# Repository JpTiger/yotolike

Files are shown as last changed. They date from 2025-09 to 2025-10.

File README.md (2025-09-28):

# "Yotolike" Music Box
A homemade audio player for kids that uses RFID cards and a Raspberry Pi Zero W 2, similar to a Yoto Player or Yoto Mini.

This is based on [jmcrory's The Pi Must Go On project](https://www.instructables.com/The-Pi-Must-Go-On-Pi-powered-RFID-Musical-Box/) and would not be anything close to possible without his work. His version differs from mine in a few respects: it uses a full size pi instead of a pi zero, uses usb spearkers insteadd of a HAT, is always plugged in instead of battery powered, doesn't have a volume knob, and doesn't have a 3D-printed case. A few of the script functions also didn't work for me without a lot of vibe-coded modifications which I suspect is due to changes in how underlying libraries are handled since he wrote his instructions.

The basic steps to making the version described in this repo are:

1. [Gather all materials](https://github.com/JpTiger/yotolike/blob/main/hardware/BOM/bom.md)
2. Put together the HATs and the pi
3. Wire everything to the exposed GPIO pins [as shown in this diagram](https://html-preview.github.io/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). This involved some soldering in my case to get the pins onto the RFID reader and to make the momentary button work jumper cables
4. Install Bookwork Raspbian lite via Raspbian imager with SSH enabled and wifi details included to a microsd and boot the pi for the first time
5. SSH in and update everything in Raspbian
6. use raspi-config to activate i2c, spi, and serial interfaces
7. edit /boot/firmware/config.txt to add/uncomment a couple lines to get the sound card working:
  - `dtparam=i2c_arm=on dtparam=audio=off`
  - `dtoverlay=wm8960-soundcard`
  - test speakers. Figuring this out took me a truly stupid amount of time so I hope it's as simple as following the above for you.
8. install python 3
  - `sudo apt-get install python3-dev python3-pip`
9. make a project directory (in my case /home/joel/musicbox)
10. use pip to install spidev and mfrc522
11. make write.py (standard version in [the jmcrory tutorial](https://www.instructables.com/The-Pi-Must-Go-On-Pi-powered-RFID-Musical-Box/))
12. use write.py to write to a card or two
13. copy over [Read.py](https://github.com/JpTiger/yotolike/blob/main/src/Read.py)
14. use [the power button setup script](https://github.com/JpTiger/yotolike/blob/main/scripts/momentary_pi_button_setup.sh)
15. create the musicbox systemd service and make it run on boot
  - `sudo systemctl daemon-reload`
  - `sudo systemctl enable musicbox.service`
  - `sudo systemctl start musicbox.service`
16. reboot, test one of the cards you wrote to see if it's all working
17. print the case, and [assemble everythig inside it](https://github.com/JpTiger/yotolike/blob/main/hardware/case/readme.md)

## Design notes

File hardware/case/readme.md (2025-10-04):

# Music Box Case (Onshape Design)

This folder has the stls from the case I designed in OnShape, but you may want to modify and export them yourself - I've got my daughter's name on mine for example, and it's likely your micro-usb to usb c adapter will have slightly different dimensions since the one I used seems to have disappeared. I'd suggest editing the part studio for the UPS HAT, which has the adapter built into it. You'll need calipers.

## Onshape link
- [You can view and edit the design in Onshape here](https://cad.onshape.com/documents/fd9248d9a8604b9996927086/w/dc4fd8e55b442b9873bcca82/e/b2e9d4da9e644a747f961f8a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)

## Exports
If you want to just try the version I used, STL files for 3D printing are included in the [`exports/`](exports/) folder:
- Case - card and reader stand.stl
- Case - Container.stl
- Case - Lid.stl
- Case - switch shield.stl
- Case - ups switch nub.stl

I suggest assembling the case by:
1. printing all parts 
2. inserting the speakers into the main container
3. attaching the RFID reader to the card and reader stand
4. instering the card and reader stand into the T-shaped slot that matches the bottom of it
5. putting the little switch shield on the switch of the UPS
6. instering the pi and hat stack (without the USB C adapter) into the space for them in the container
7. insterting the USB C adapter in from the hole of the container into the microusb slot
8. using poster putty or(if you're confident and dexterous) hot glue or to attach the clear PETG filament to the LEDs on the pi and UPS on one end and to the holes in the container on the other. I interted a long strand through the holes, poked it with poster putty on a toothpick until it stuck direclty onto the LEDs, then trimmed the other end of the filament at the hole end.
9. Installing the rotary encoder, tightenting, and then the same with the momentary button
10. adding the ups switch nub to the switch from the outside
11. adding the lid

If your rotraty encoder didn't come with a knob, you may need to print that as well. [This one worked for me.](https://www.thingiverse.com/thing:2549137)

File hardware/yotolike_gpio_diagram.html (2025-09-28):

# 🔌 Raspberry Pi GPIO Connection Diagram

Raspberry Pi 40-Pin GPIO Header

1 3V3

3.3V Power - RFID Reader

2 5V

3 SDA

GPIO 2 - WM8960 I2C SDA

4 5V

5 SCL

GPIO 3 - WM8960 I2C SCL + Button Normal Open

6 GND

Ground - Button Common

7 4

GPIO 4 - Button Normal Closed

8 14

GPIO 14 - LED Anode

9 GND

10 15

11 17

GPIO 17 - WM8960 Button

12 18

GPIO 18 - WM8960 I2S CLK

13 27

14 GND

15 22

16 23

GPIO 23 - RFID SCK

17 3V3

3.3V Power - Rotary Encoder VCC

18 24

GPIO 24 - RFID SDA

19 10

GPIO 10 - RFID MOSI

20 GND

21 9

GPIO 9 - RFID MISO

22 25

GPIO 25 - RFID RST

23 11

24 8

25 GND

26 7

27 0

28 1

29 5

30 GND

Ground - RFID Reader

31 6

32 12

33 13

GPIO 13 - Rotary Encoder SW

34 GND

Ground - Rotary Encoder

35 19

GPIO 19 - WM8960 LRCLK

36 16

GPIO 16 - Rotary Encoder DT

37 26

GPIO 26 - Rotary Encoder CLK

38 20

GPIO 20 - WM8960 ADC

39 GND

Ground - LED Cathode

40 21

GPIO 21 - WM8960 DAC

### 🏷️ RFID Reader (RC522)

SDA Pin 18 (GPIO 24)

SCK Pin 16 (GPIO 23)

MOSI Pin 19 (GPIO 10)

MISO Pin 21 (GPIO 9)

RST Pin 22 (GPIO 25)

3.3V Pin 1

GND Pin 30

### 🎵 WM8960 Audio HAT

SDA (I2C) Pin 3 (GPIO 2)

SCL (I2C) Pin 5 (shared) (GPIO 3)

CLK (I2S) Pin 12 (GPIO 18)

LRCLK (I2S) Pin 35 (GPIO 19)

ADC (I2S) Pin 38 (GPIO 20)

DAC (I2S) Pin 40 (GPIO 21)

BUTTON Pin 11 (GPIO 17)

### 🎛️ Rotary Encoder

CLK Pin 37 (GPIO 26)

DT Pin 36 (GPIO 16)

SW (Button) Pin 33 (GPIO 13)

VCC Pin 17 (3.3V)

GND Pin 34

### 🔘 Button & LED

LED Anode (+) (Red) Pin 8 (GPIO 14)

LED Cathode (-) (Black) Pin 39 (GND)

Button Normal Close (Blue) Pin 7 (GPIO 4)

Button Normal Open (Green) Pin 5 (shared) (GPIO 3)

Button Ground (Yellow) Pin 6 (GND)

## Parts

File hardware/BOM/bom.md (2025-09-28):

# Bill of Materials
In other words, this is everything I bought for the project.

| Item | Qty | Example Link | Notes |
|---|----:|---|---|
| Raspberry Pi Zero 2 W (with soldered header) | 1 | [PiShop US](https://www.pishop.us/product/raspberry-pi-zero-2w-with-headers/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) | Main controller |
| Waveshare WM8960 Audio HAT (with speakers) | 1 | [Waveshare](https://www.waveshare.com/wm8960-audio-hat.htm) | Stereo audio output |
| Waveshare UPS HAT (C) | 1 | [Waveshare](https://www.waveshare.com/ups-hat-c.htm) | Battery backup and safe shutdown |
| Rotary Encoder | 1 | [eBay](https://www.ebay.com/itm/314583808281) | For volume or menu control |
| Momentary Push Button | 1 | [eBay](https://www.ebay.com/itm/334710109104?var=544357275466) | Power or shutdown button |
| Mifare IC Card (13.56 MHz) | 3+ | [eBay](https://www.ebay.com/itm/196037533459) | RFID cards/tags for triggering audio |
| MFRC-522 RC522 RFID Reader/Writer | 1 | [eBay](https://www.ebay.com/itm/315803761536) | Reads the Mifare cards |
| Female-to-Female Jumper Wires (GPIO) | ~20 | [eBay](https://www.ebay.com/itm/324089639653?var=513138028264) | For connecting HATs, reader, and buttons |
| USB C Female to Micro USB Male adapter | 1 | [eBay](https://www.ebay.com/itm/134434291262?var=433897534343) | Lets you charge via USB C instead of MicroUSB |

As with any raspberry pi project, you'll also want a microSD card and a way to write to it, as well as an adequate power supply(/charging cable).

I also got a few inches of clear PETG filament to act as cut-rate fiberoptics for the LEDs, but haven't yet gotten around to attaching them.

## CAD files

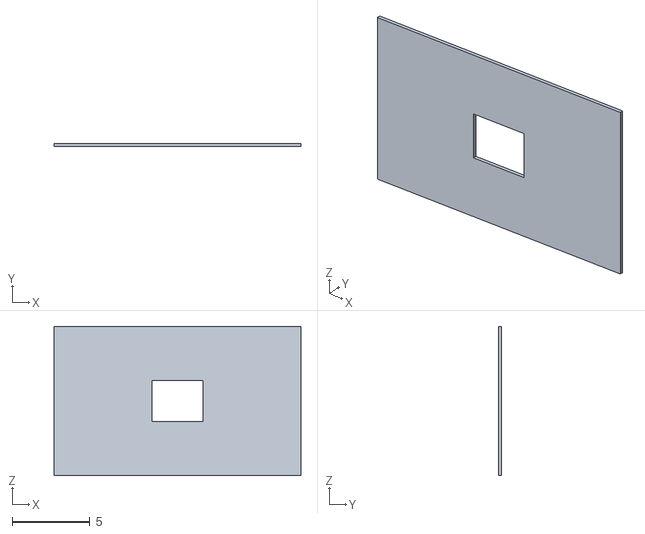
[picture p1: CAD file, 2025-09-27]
hardware/case/exports/Case - switch shield.stl
15.9 x 0.2 x 9.62

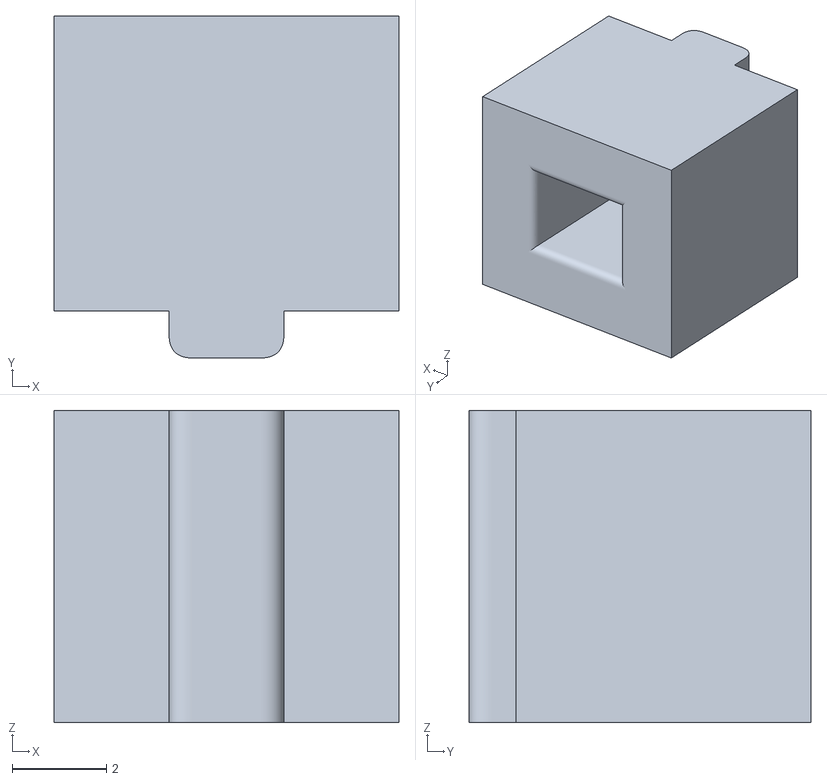
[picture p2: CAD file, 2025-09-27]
hardware/case/exports/Case - ups switch nub.stl
7.31 x 7.25 x 6.62

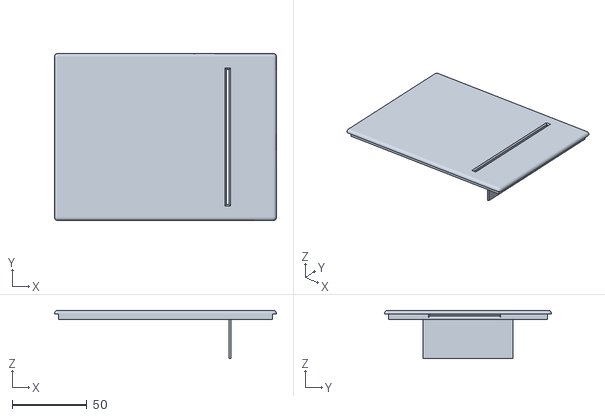
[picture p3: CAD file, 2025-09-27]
hardware/case/exports/Case - Lid.stl
149.0 x 112.0 x 32.5

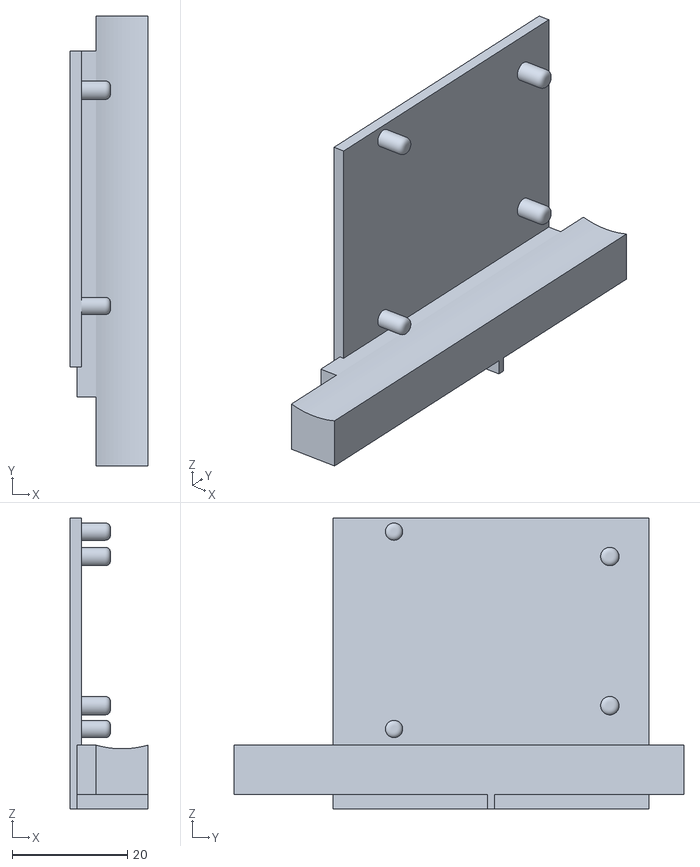
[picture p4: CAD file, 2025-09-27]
hardware/case/exports/Case - card and reader stand.stl
13.5 x 78.1 x 50.5

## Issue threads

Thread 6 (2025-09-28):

lid guide need reinforcing

JpTiger, 2025-09-28:
Kid stuffed a card too hard into the slot and it broke the guide on one side of the lid. Printing a reinforcing piece now but design of lid needs something to strengthen it

JpTiger, 2025-10-04:
Extruded a reinforcing block at the base of the guide in the lid in onshape

Closed 2025-10-04.

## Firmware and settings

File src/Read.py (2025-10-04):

#!/usr/bin/env python3
"""
Enhanced RFID Musical Box with Rotary Encoder Volume Control - FIXED VERSION
- Rotary encoder on GPIO 26 (CLK), GPIO 16 (DT), GPIO 13 (SW)
- Volume control via encoder rotation
- Pause/Resume via encoder button press
- RFID tag detection for song selection
- Supports both WAV and MP3 files
- Proper GPIO mode configuration and shutdown handling
"""
import time
from time import sleep
import pygame
import sys
import RPi.GPIO as GPIO
from mfrc522 import SimpleMFRC522
import re
import os
import signal
import threading

class RotaryEncoder:
    def __init__(self, clk_pin, dt_pin, sw_pin):
        """Initialize rotary encoder with BCM GPIO numbers"""
        self.clk_pin = clk_pin  # GPIO 26
        self.dt_pin = dt_pin    # GPIO 16
        self.sw_pin = sw_pin    # GPIO 13
        
        # Set up GPIO pins with proper pull-ups
        GPIO.setup(self.clk_pin, GPIO.IN, pull_up_down=GPIO.PUD_UP)
        GPIO.setup(self.dt_pin, GPIO.IN, pull_up_down=GPIO.PUD_UP)
        GPIO.setup(self.sw_pin, GPIO.IN, pull_up_down=GPIO.PUD_UP)
        
        # Track previous states
        self.clk_last_state = GPIO.input(self.clk_pin)
        self.dt_last_state = GPIO.input(self.dt_pin)
        self.sw_last_state = GPIO.input(self.sw_pin)
        
        self.last_button_time = 0
        self.last_rotation_time = 0
        self.rotation_counter = 0
        
        # Wait a moment for pins to stabilize
        time.sleep(0.1)
        
        print(f"🔧 Encoder setup - CLK: GPIO{self.clk_pin}, DT: GPIO{self.dt_pin}, SW: GPIO{self.sw_pin}")
        print(f"🔧 Initial states - CLK: {self.clk_last_state}, DT: {self.dt_last_state}, SW: {self.sw_last_state}")
    
    def check_rotation(self):
        """Check for encoder rotation and return direction (1, -1, or 0)"""
        current_time = time.time()
        
        # Read current states
        clk_state = GPIO.input(self.clk_pin)
        dt_state = GPIO.input(self.dt_pin)
        
        # Check if CLK pin has changed (falling edge detection)
        if clk_state != self.clk_last_state and clk_state == 0:  # Falling edge
            # Debounce check
            if current_time - self.last_rotation_time > 0.005:
                # Determine direction based on DT state when CLK goes low
                if dt_state == 0:
                    direction = -1   # Counter-clockwise
                else:
                    direction = 1  # Clockwise
                
                self.last_rotation_time = current_time
                self.rotation_counter += 1
                
                print(f"🔄 Rotation #{self.rotation_counter}: {direction} (CLK: {clk_state}, DT: {dt_state})")
                
                # Update states
                self.clk_last_state = clk_state
                self.dt_last_state = dt_state
                return direction
        
        # Update states even if no rotation detected
        self.clk_last_state = clk_state
        self.dt_last_state = dt_state
        return 0
    
    def check_button(self):
        """Check for button press and return True if pressed"""
        current_time = time.time()
        sw_state = GPIO.input(self.sw_pin)
        
        # Detect falling edge (button press)
        if sw_state == 0 and self.sw_last_state == 1:
            # Debounce check
            if current_time - self.last_button_time > 0.3:
                self.last_button_time = current_time
                self.sw_last_state = sw_state
                print("🔘 Button pressed!")
                return True
        
        self.sw_last_state = sw_state
        return False

    def is_pressed(self):
        return GPIO.input(self.sw_pin) == 0

class MusicBox:
    def __init__(self):
        self.reader = SimpleMFRC522()
        self.current_text = "Start"  # default label
        # Ensure attribute always exists even before first play
        self.current_text = self.current_text or ""
        self.volume = 0.5  # Start at 50% volume
        self.is_paused = False
        self.is_playing = False
        self.running = True
        self.shutdown_requested = False

        # Playback tracking
        self.current_track_path = None
        self.current_pos_sec = 0.0
        self.last_status_update_time = time.time()
        self.seek_step_sec = 10  # seconds per detent when seeking
        self.paused_uid = None  # track UID that caused a pause due to removal

        # RFID presence debouncing (required for stable presence)
        self.current_uid = None          # UID considered 'present'
        self.uid_last_seen = 0.0         # last time we saw the current UID
        self.remove_grace = 1.0          # seconds with no reads before 'removed'

        # NEW: RFID edge state to avoid replays / pause->restart bugs
        self.last_uid = None     # last seen RFID UID (or None if no card present)
        self.armed = True        # only trigger playback once per card-present cycle
        
        # Initialize pygame mixer
        try:
            pygame.mixer.pre_init(frequency=22050, size=-16, channels=2, buffer=1024)
            pygame.mixer.init()
            pygame.mixer.music.set_volume(self.volume)
            print("✅ Audio system initialized")
            # Startup sound setup
            self.startup_channel = None
            self.startup_sound_path = os.path.join(os.path.dirname(__file__), "startup.mp3")
        except Exception as e:
            print(f"❌ Audio initialization failed: {e}")
            raise
        
        # Set up rotary encoder
        try:
            self.encoder = RotaryEncoder(
                clk_pin=26,
                dt_pin=16,
                sw_pin=13
            )
            print("✅ Rotary encoder initialized")
        except Exception as e:
            print(f"❌ Encoder initialization failed: {e}")
            raise
        
        # Signal handlers
        signal.signal(signal.SIGINT, self._signal_handler)
        signal.signal(signal.SIGTERM, self._signal_handler)
        
        print("\n🎵 RFID Musical Box with Volume Control Ready!")

        # Play startup sound non-blocking, if present
        self.play_startup_sound()
    
    def _signal_handler(self, signum, frame):
        print(f"\n🛑 Received signal {signum}, initiating graceful shutdown.")
        self.shutdown_requested = True
        self.running = False
    
    def handle_volume_change(self, direction):
        volume_step = 0.05
        if direction > 0:
            new_volume = min(1.0, self.volume + volume_step)
        else:
            new_volume = max(0.0, self.volume - volume_step)
        if new_volume != self.volume:
            self.volume = new_volume
            pygame.mixer.music.set_volume(self.volume)
            print(f"🔊 Volume: {int(self.volume*100)}%")
    
    def handle_pause_resume(self):
        if self.is_playing:
            if self.is_paused:
                pygame.mixer.music.unpause()
                self.is_paused = False
                print("▶️  Music resumed")
            else:
                pygame.mixer.music.pause()
                self.is_paused = True
                print("⏸️  Music paused")
        else:
            print("❌ No music currently playing")
    
    def play_track(self, track_name, start_pos: float = 0.0):
        try:
            # Revert to hardcoded path
            base_path = os.path.join(os.path.dirname(__file__), track_name)
            for ext in ['.wav', '.mp3']:
                filepath = base_path + ext
                if os.path.exists(filepath):
                    if pygame.mixer.music.get_busy():
                        pygame.mixer.music.stop()
                        time.sleep(0.1)
                    pygame.mixer.music.load(filepath)
                    pygame.mixer.music.set_volume(self.volume)
                    # Fade out startup sound if still playing
                    try:
                        if getattr(self, "startup_channel", None) and self.startup_channel.get_busy():
                            self.startup_channel.fadeout(300)
                    except Exception:
                        pass

                    if start_pos and start_pos > 0:
                        try:
                            pygame.mixer.music.play(start=start_pos)
                        except TypeError:
                            pygame.mixer.music.play()
                            pygame.mixer.music.set_pos(start_pos)
                    else:
                        pygame.mixer.music.play()
                    self.is_playing = True
                    self.is_paused = False
                    self.current_track_path = filepath
                    self.current_pos_sec = float(start_pos) if start_pos else 0.0
                    self.last_status_update_time = time.time()
                    print(f"🔊 Playing {track_name} (start={start_pos:.1f}s)")
                    return True
            print(f"❌ No audio file found for {track_name}")
            return False
        except Exception as e:
            print(f"❌ Error playing {track_name}: {e}")
            return False
    
    def check_music_status(self):
        now = time.time()
        if self.is_playing and not self.is_paused and pygame.mixer.music.get_busy():
            delta = now - self.last_status_update_time
            if delta > 0:
                self.current_pos_sec += delta
        self.last_status_update_time = now
        if self.is_playing and not self.is_paused and not pygame.mixer.music.get_busy():
            print("🎵 Song finished")
            self.is_playing = False
    
    def handle_seek(self, direction):
        """Seek within the current track; press + rotate to scrub."""
        if not self.current_track_path:
            print("↔️  Seek ignored (no track loaded)")
            return
        step = self.seek_step_sec * (1 if direction > 0 else -1)
        new_pos = max(0.0, self.current_pos_sec + step)
        was_playing = self.is_playing and not self.is_paused
        was_paused = self.is_paused
        try:
            pygame.mixer.music.stop()
            pygame.mixer.music.load(self.current_track_path)
            pygame.mixer.music.set_volume(self.volume)
            try:
                pygame.mixer.music.play(start=new_pos)
            except TypeError:
                pygame.mixer.music.play()
                pygame.mixer.music.set_pos(new_pos)
            self.current_pos_sec = new_pos
            self.last_status_update_time = time.time()
            if was_paused:
                pygame.mixer.music.pause()
                self.is_paused = True
                self.is_playing = True
                print(f"⏱️  Scrubbed to {new_pos:.1f}s (paused)")
            elif was_playing:
                self.is_playing = True
                self.is_paused = False
                print(f"⏩⏪ Seek to {new_pos:.1f}s")
            else:
                self.is_playing = True
                self.is_paused = False
                print(f"▶️  Restarted at {new_pos:.1f}s after finish")
        except Exception as e:
            print(f"⚠️ Seek error: {e}")

    def play_startup_sound(self):
        try:
            if os.path.exists(self.startup_sound_path):
                snd = pygame.mixer.Sound(self.startup_sound_path)
                snd.set_volume(self.volume)
                self.startup_channel = snd.play()
            else:
                # No startup sound file; skip silently
                pass
        except Exception as e:
            print(f"⚠️ Startup sound error: {e}")

    def run(self):
        try:
            rfid_check_time = 0
            status_check_time = 0
            while self.running and not self.shutdown_requested:
                current_time = time.time()

                direction = self.encoder.check_rotation()
                if direction != 0:
                    if self.encoder.is_pressed():
                        self.handle_seek(direction)
                    else:
                        self.handle_volume_change(direction)
                # Ignore simple button taps for now
                # if self.encoder.check_button(): pass
                if current_time - status_check_time > 1.0:
                    self.check_music_status()
                    status_check_time = current_time
                # RFID edge-triggered logic (debounced)
                if current_time - rfid_check_time > 0.5:
                    try:
                        tag_id, text = self.reader.read_no_block()
                        seen_uid = str(tag_id) if tag_id is not None else None
                        if seen_uid is not None:
                            if self.current_uid is None:
                                # Rising edge: new card detected
                                self.current_uid = str(seen_uid)
                                self.uid_last_seen = current_time
                                # Resume first if this is the same UID we paused on
                                if self.is_paused and self.current_track_path and str(self.paused_uid) == str(seen_uid):
                                    pygame.mixer.music.unpause()
                                    self.is_paused = False
                                    self.is_playing = True
                                    self.last_status_update_time = time.time()
                                    print("▶️  Resumed after reinsert")
                                    self.armed = False
                                else:
                                    print(f"\n💳 Card added/changed: UID={seen_uid}")
                                    if text:
                                        text = text.strip()
                                    track = re.sub(r"[^A-Za-z0-9_-]", "", text or "") if text else ""
                                    if track:
                                        if self.play_track(track, start_pos=0.0):
                                            self.current_text = text
                                            self.paused_uid = None
                                    self.armed = False
                            else:
                                # Card still present; check if changed UID
                                self.uid_last_seen = current_time
                                if str(seen_uid) != str(self.current_uid):
                                    self.current_uid = str(seen_uid)
                                    print(f"\n💳 Card added/changed: UID={seen_uid}")
                                    if text:
                                        text = text.strip()
                                    track = re.sub(r"[^A-Za-z0-9_-]", "", text or "") if text else ""
                                    if track:
                                        if self.play_track(track, start_pos=0.0):
                                            self.current_text = text
                                            self.paused_uid = None
                                        self.armed = False
                        else:
                            # No UID this poll; only consider removal after grace period
                            if self.current_uid is not None and (current_time - self.uid_last_seen) > self.remove_grace:
                                print("💳 Card removed")
                                self.armed = True
                                if self.is_playing and not self.is_paused:
                                    pygame.mixer.music.pause()
                                    self.is_paused = True
                                    # Remember last paused UID (so the same card resumes)
                                    self.paused_uid = str(self.current_uid)
                                    print("⏸️  Paused on card removal")
                                self.current_uid = None
                        rfid_check_time = current_time
                    except Exception as e:
                        print(f"⚠️ RFID read error: {e}")
                        rfid_check_time = current_time
                time.sleep(0.01)
        finally:
            self.cleanup()
    
    def cleanup(self):
        print("🧹 Cleanup starting.")
        try:
            if pygame.mixer.get_init():
                pygame.mixer.music.stop()
                pygame.mixer.quit()
        except: pass
        try:
            GPIO.cleanup()
        except: pass
        print("✅ Cleanup complete")

def main():
    GPIO.setwarnings(False)
    GPIO.setmode(GPIO.BCM)
    musicbox = MusicBox()
    musicbox.run()

if __name__ == "__main__":
    main()

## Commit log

2025-09-22 Create bom.md
    Created a bill of materials
2025-09-27 Create readme.md
    Adding a readme for the case files
2025-09-27 Add files via upload
    Added the version of the case that I printed
    [Case - Lid.stl, Case - card and reader stand.stl, Case - switch shield.stl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]
2025-09-28 Rename BOM/bom.md to hardware/BOM/bom.md
    consolidating hardware related files
2025-09-28 Update readme.md
    Added steps for assembly
2025-09-28 Add files via upload
    Wiring diagram
2025-09-28 Update README.md
    add bit about soldering
2025-10-04 Updated read.py
    Added additional features:
    - Removing card pauses playback, reinserting resumes
    - Depressing rotary dial and turning scrubs forward/back in playback
    -startup tone added for when device is ready
    Bug fixes/ QoL enhancements:
    - playback does not loop when card is left in device
    - starting volume lowered to 50%
    - new pause trigger obviates playback starting from beginning on pause
    [Read.py]
